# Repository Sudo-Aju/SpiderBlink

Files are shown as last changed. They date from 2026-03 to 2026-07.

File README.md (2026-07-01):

<div align="center">

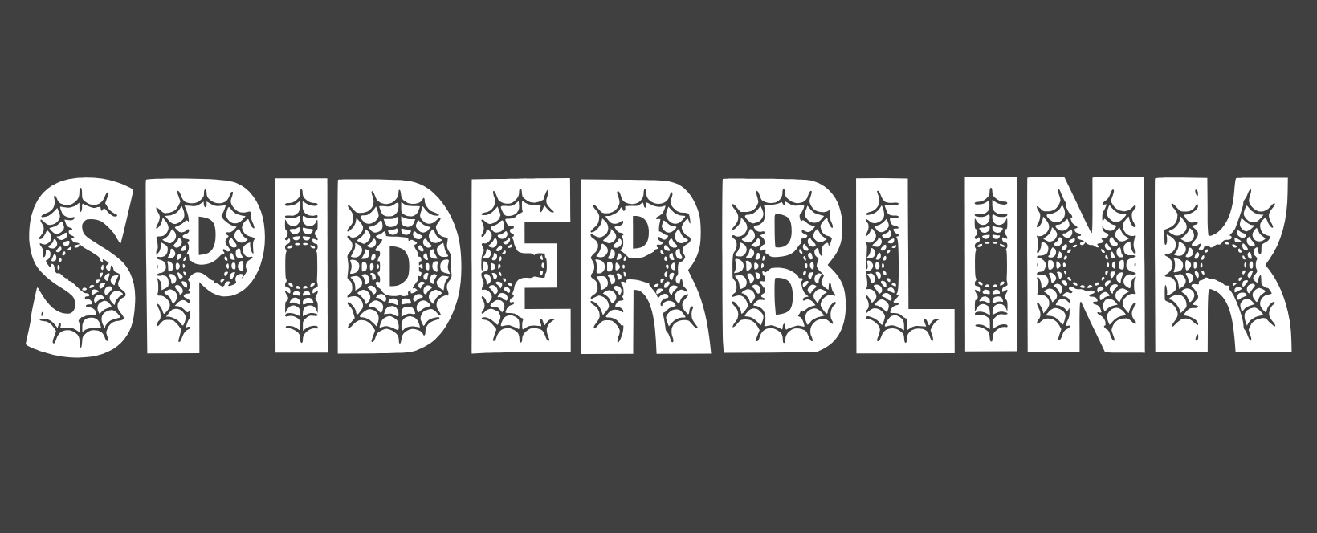
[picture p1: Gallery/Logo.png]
swlogo
# 

A Tiny LED Blinker in Shape of a Spiderweb

<p>



</p>

### _Blinks every time it gets the tingle._

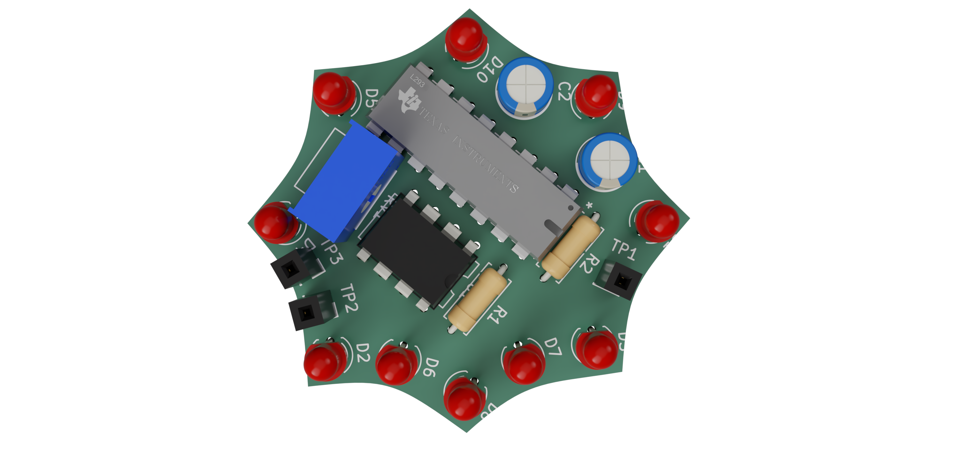
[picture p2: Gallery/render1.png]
  

</p>
</div>

# Overview

**SpiderBlink** is a 555 LED chaser board that blinks 10 LEDs in a variable speed sequence using a **NE555P** timer IC and a **CD4017** decade counter. I built this as a beginner PCB project to learn schematic design, PCB routing, and hands-on soldering.

---

# Gallery

<div align="center">

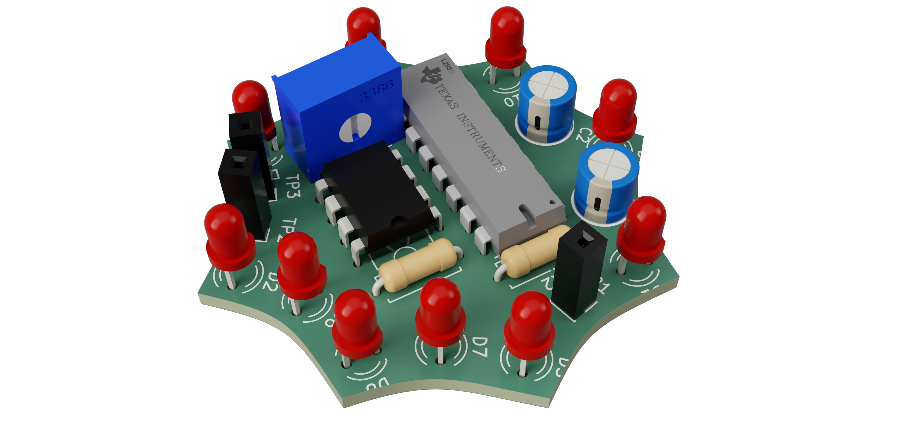
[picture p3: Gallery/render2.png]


</div>

---

# Zine

<div align="center">

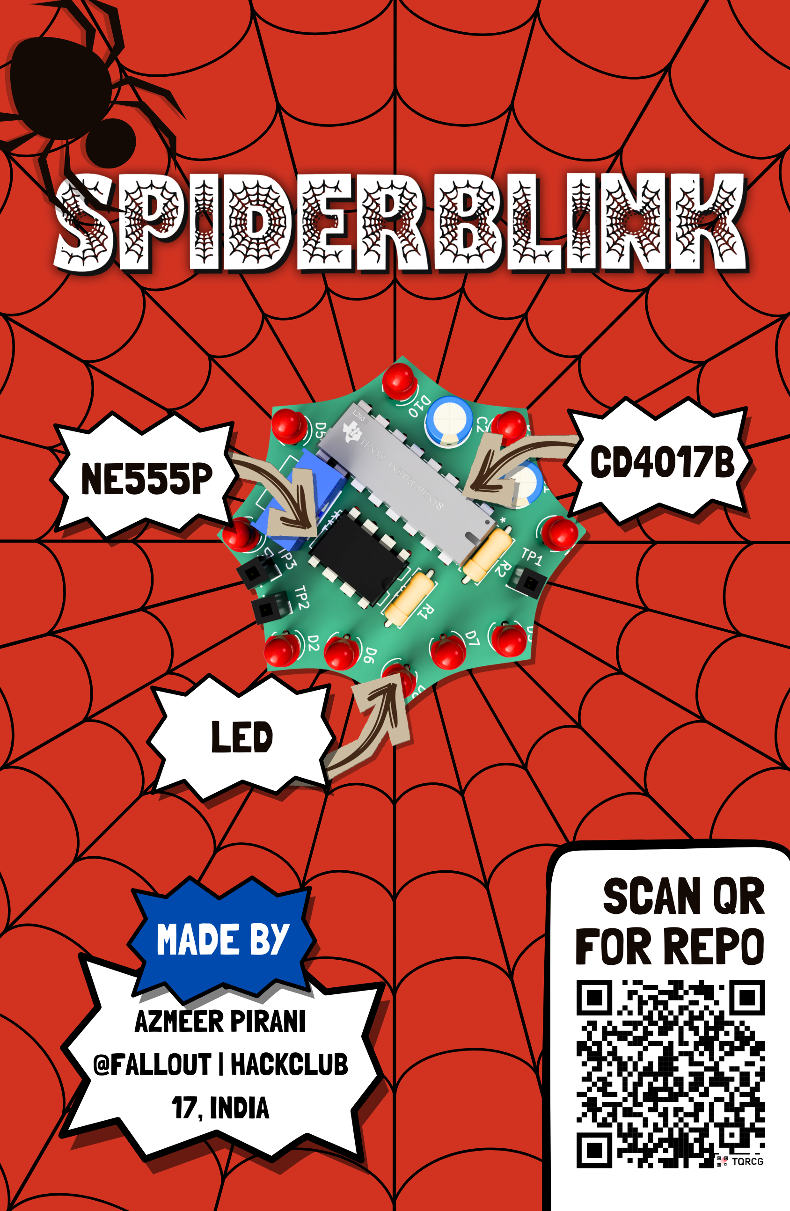
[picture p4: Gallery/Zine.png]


</div>

---

# Motivation

I wanted to dvelve deeper into embedded electronics, so thought this might be the chance for me to understand more about ICs, Timers and Oscillators

---

## Bill of Materials

|Reference|Description |Manufacturer |MPN |Quantity|Supplier |Unit Price (USD)|Extended Price (USD)|Product Link |
|---|---|---|---|---|---|---|---|---|
|C1 |0.01 µF Ceramic Capacitor |Murata |GRM188R71H103KA01D|1 |Murata |0.10 |0.10 |https://www.murata.com/en-global/products/productdetail?partno=GRM188R71H103KA01D|
|C2 |1 µF Ceramic Capacitor |Murata |GRM188R60J105KA01D|1 |Murata |0.15 |0.15 |https://www.murata.com/en-global/products/productdetail?partno=GRM188R60J105KA01D|
|D1-D10 |5 mm Red LED |Kingbright |WP7113ID |10 |Kingbright |0.18 |1.80 |https://www.kingbrightusa.com/product.asp?catalog_name=LED&product_id=WP7113ID |
|R1 |1 kΩ 1/4W Through-Hole Resistor |Yageo |CFR-25JB-52-1K |1 |Yageo |0.02 |0.02 |https://www.yageo.com/en/Product/Search?partNumber=CFR-25JB-52-1K |
|R2 |470 Ω 1/4W Through-Hole Resistor|Yageo |CFR-25JB-52-470R  |1 |Yageo |0.02 |0.02 |https://www.yageo.com/en/Product/Search?partNumber=CFR-25JB-52-470R |
|RV1 |50 kΩ Trimmer Potentiometer |Bourns |3362P-1-503LF |1 |Bourns |1.25 |1.25 |https://www.bourns.com/products/trimpot-trimming-potentiometers/product/3362 |
|U1 |NE555P Timer IC |Texas Instruments|NE555P |1 |Texas Instruments|0.60 |0.60 |https://www.ti.com/product/NE555 |
|U2 |CD4017B Decade Counter |Texas Instruments|CD4017B |1 |Texas Instruments|0.75 |0.75 |https://www.ti.com/product/CD4017B |

---

# Features

- Heartbeat: An NE555 timer generates the clock signal.
- Speed Control: A 50kΩ potentiometer adjusts the LED flashing speed.
- Sequencer: A CD4017 decade counter cycles the signal through 10 steps.
- Rotating Effect: 10 LEDs arranged in a circular pattern for a rotating effect.

---

# PCB Design

The PCB was designed with the reference of a piderweb, more specifically Spiderman

## PCB
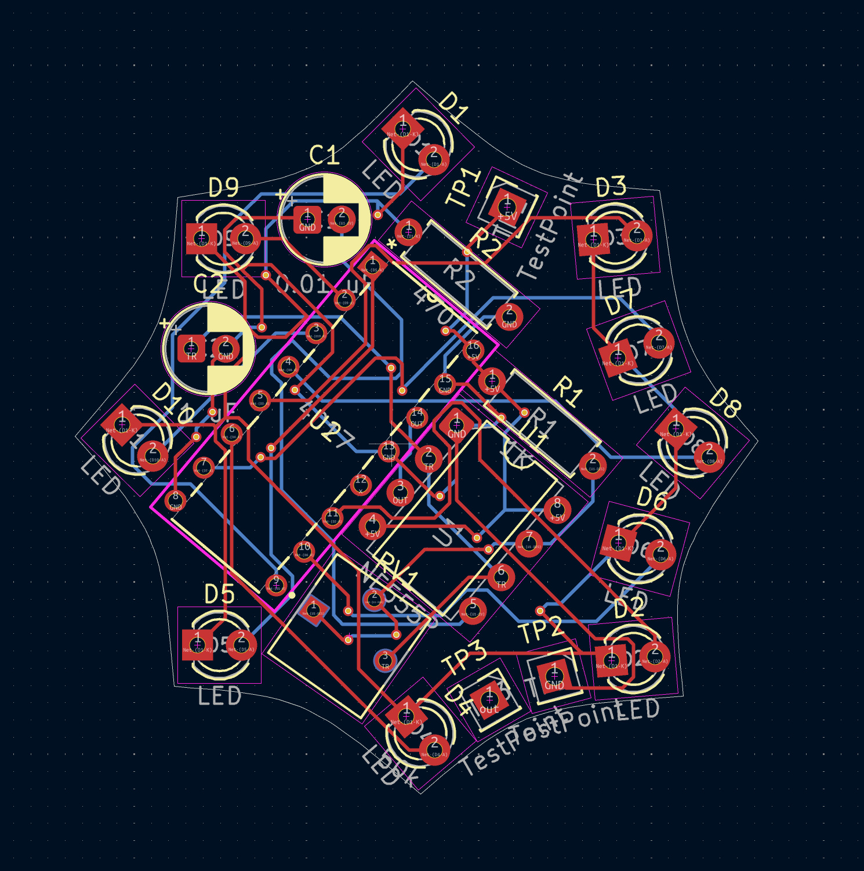
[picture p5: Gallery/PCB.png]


## Schematic
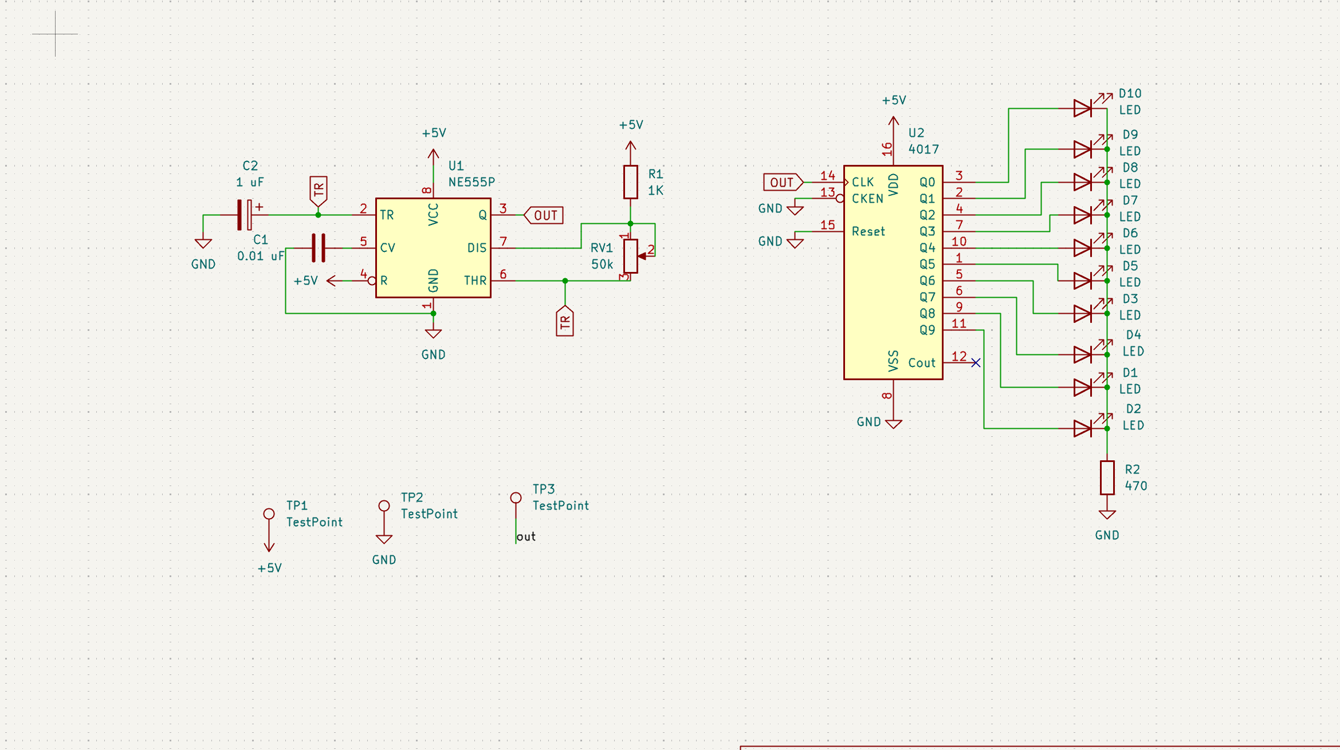
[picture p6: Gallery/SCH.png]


---

# Current Status

- [X] Initial Concept
- [X] Schematic Design
- [X] PCB Design
- [X] Hardware Validation
- [ ] Functional Testing
- [ ] Community Evaluation 

---

# Repository Structure

```bash
SpiderBlink/
├── PCB/
├── BOM.csv
├── Gallery/
└── README.md
```

---

# Assemble Guide

## 1. Order the PCB

Navigate to:

```bash
./PCB/Gerber.zip
```

Upload the Gerber files to your preferred PCB manufacturer.

---

## 2. Order Components

All required components can be found in:

```bash
./PCB/BOM.csv
```

---

## 3. Solder the Components

Recommended assembly should follow a low-profile to high-profile sequence to simplify alignment and reduce rework.

Suggested order:

1. 1/4W Resistors (R1, R2)
2. Ceramic Capacitors (C1, C2)
3. NE555P
4. 5mm LEDs (D1–D10)

---

## 4. Inspect the Board

Before powering:
- Check for shorts
- Verify connections
- Inspect power rails

---

# Contributing

Contributions, suggestions, and feedback are welcome.

If you'd like to improve SpiderBlink:

```bash
git clone https://github.com/Sudo-Aju/SpiderBlink.git
cd SpiderBlink
```

1. Create a feature branch
2. Make your changes
3. Commit your work
4. Open a pull request

---

# Creator

### Azmeer Pirani

Built with ❤️ for:
- Embedded Systems
- PCB Design
- Open Source Hardware
- Tiny Things

---

# License

This project is licensed under the MIT License.

---

<div align="center">

## SPIDERBLINK

### _Blinks every time it gets the tingle._

</div>

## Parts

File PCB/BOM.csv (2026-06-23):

Reference | Description | Manufacturer | MPN | Quantity | Supplier | Unit Price | Currency | Product Link | Extended Price
C1 | 0.01 µF Ceramic Capacitor | Murata | GRM188R71H103KA01D | 1 | Murata | 0.10 | USD | https://www.murata.com/en-global/products/productdetail?partno=GRM188R71H103KA01D | 0.1
C2 | 1 µF Ceramic Capacitor | Murata | GRM188R60J105KA01D | 1 | Murata | 0.15 | USD | https://www.murata.com/en-global/products/productdetail?partno=GRM188R60J105KA01D | 0.15
D1–D10 | 5 mm Red LED | Kingbright | WP7113ID | 10 | Kingbright | 0.18 | USD | https://www.kingbrightusa.com/product.asp?catalog_name=LED&product_id=WP7113ID | 1.7999999999999998
R1 | 1 kΩ 1/4W Resistor | Yageo | CFR-25JB-52-1K | 1 | Yageo | 0.02 | USD | https://www.yageo.com/en/Product/Search?partNumber=CFR-25JB-52-1K | 0.02
R2 | 470 Ω 1/4W Resistor | Yageo | CFR-25JB-52-470R | 1 | Yageo | 0.02 | USD | https://www.yageo.com/en/Product/Search?partNumber=CFR-25JB-52-470R | 0.02
RV1 | 50 kΩ Trimmer Potentiometer | Bourns | 3362P-1-503LF | 1 | Bourns | 1.25 | USD | https://www.bourns.com/products/trimpot-trimming-potentiometers/product/3362 | 1.25
U1 | NE555P Timer IC | Texas Instruments | NE555P | 1 | Texas Instruments | 0.60 | USD | https://www.ti.com/product/NE555 | 0.6
U2 | CD4017B Decade Counter | Texas Instruments | CD4017B | 1 | Texas Instruments | 0.75 | USD | https://www.ti.com/product/CD4017B | 0.75

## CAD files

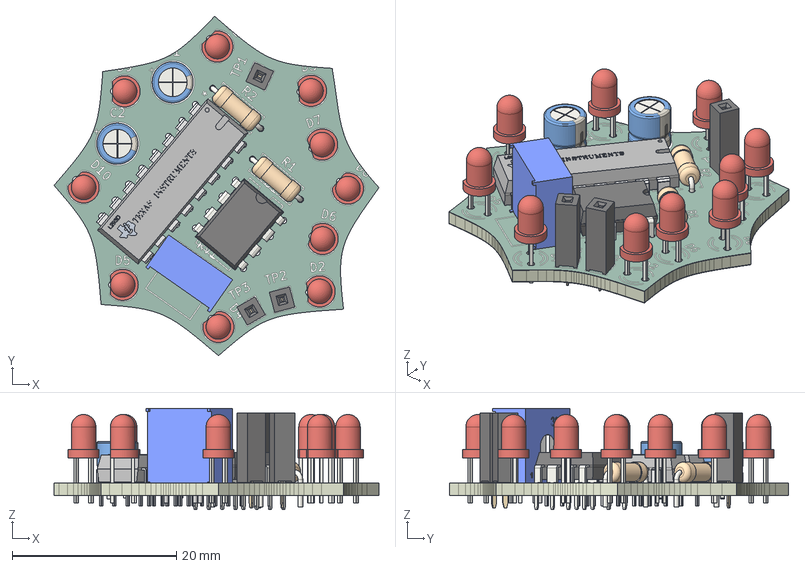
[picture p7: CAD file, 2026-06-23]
PCB/PCB.step
39.6 x 41.4 x 12.3 mm
CP_Radial_D50mm_P200mm x 2
LED_D3.0mm x 10
PinSocket_1x01_P2.54mm_Vertical x 3
IC 16 DIP
IC Leg x 16
L293D
Texas Instrument Logo
Trimpot 3386H v1
R_Axial_DIN0207_L63mm_D25mm_P762mm_Horizontal x 2
DIP-8_W7.62mm
Spider-unsaved-export-1Loybe_silkscreen
Spider-unsaved-export-1Loybe_soldermask x 2
Spider-unsaved-export-1Loybe_PCB

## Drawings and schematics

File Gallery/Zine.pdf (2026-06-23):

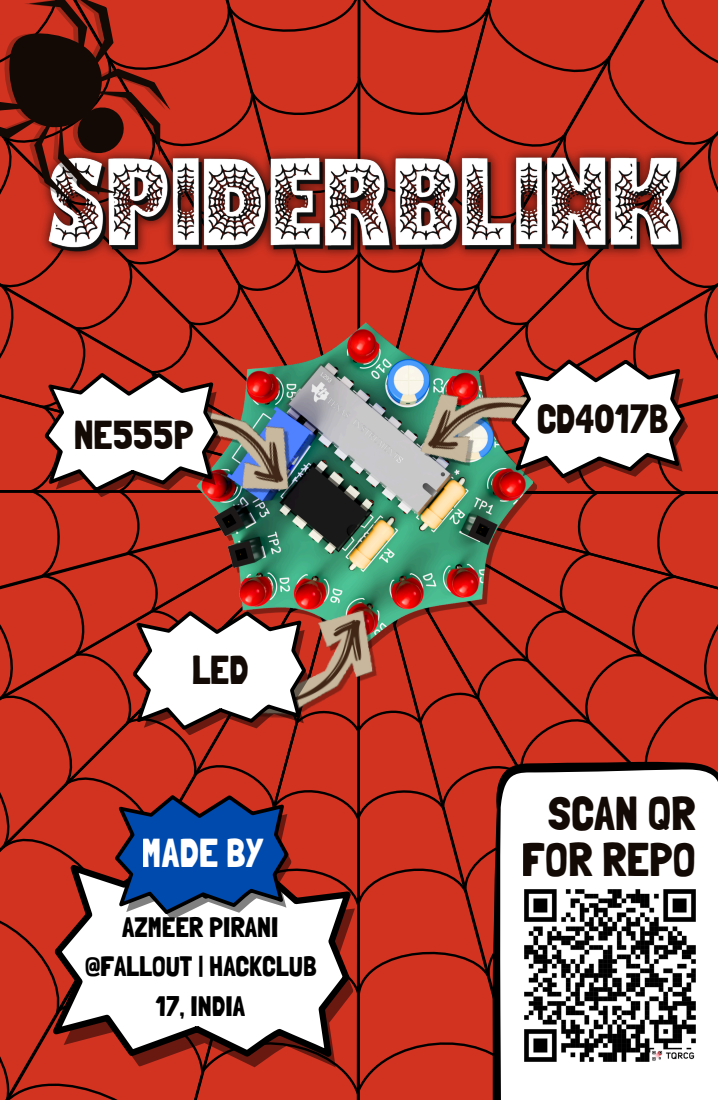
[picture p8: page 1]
AZMEER PIRANI @FALLOUT | HACKCLUB 17, INDIA; MADE BY; SCAN QR FOR REPO; LED

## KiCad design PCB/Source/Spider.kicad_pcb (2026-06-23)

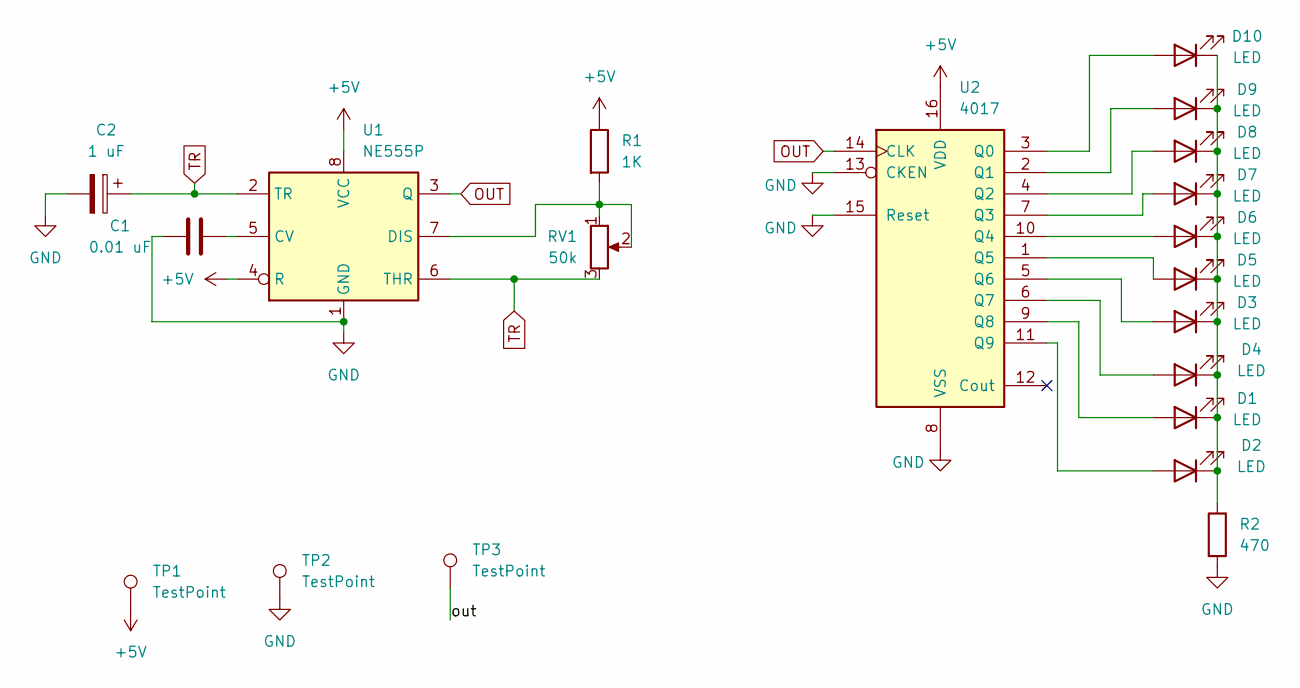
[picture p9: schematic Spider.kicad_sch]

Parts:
C1: 0.01 uF; CP_Radial_D5.0mm_P2.00mm
C2: 1 uF; CP_Radial_D5.0mm_P2.00mm
D1, D2, D3, D4, D5, D6, D7, D8, D9, D10: LED; LED_D3.0mm
R1: 1K; R_Axial_DIN0207_L6.3mm_D2.5mm_P7.62mm_Horizontal
R2: 470; R_Axial_DIN0207_L6.3mm_D2.5mm_P7.62mm_Horizontal
RV1: 50k; TRIM_3362P-1-102
TP1, TP2, TP3: TestPoint; PinSocket_1x01_P2.54mm_Vertical
U1: NE555P; DIP-8_W7.62mm
U2: 4017; N16

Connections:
+5V: R1.1, TP1.1, U1.4 (R), U1.8 (VCC), U2.16 (VDD)
/out: TP3.1
GND: C1.1, C2.2, R2.2, TP2.1, U1.1 (GND), U2.8 (VSS), U2.13 (CKEN), U2.15 (Reset)
unnamed: D1.2 (A), U2.9 (Q8)
unnamed: D1.1 (K), D2.1 (K), D3.1 (K), D4.1 (K), D5.1 (K), D6.1 (K), D7.1 (K), D8.1 (K), D9.1 (K), D10.1 (K), R2.1
unnamed: D2.2 (A), U2.11 (Q9)
unnamed: D3.2 (A), U2.5 (Q6)
unnamed: D4.2 (A), U2.6 (Q7)
unnamed: D5.2 (A), U2.1 (Q5)
unnamed: D6.2 (A), U2.10 (Q4)
unnamed: D7.2 (A), U2.7 (Q3)
unnamed: D8.2 (A), U2.4 (Q2)
unnamed: D9.2 (A), U2.2 (Q1)
unnamed: D10.2 (A), U2.3 (Q0)
unnamed: C1.2, U1.5 (CV)
unnamed: R1.2, RV1.1, RV1.2, U1.7 (DIS)
OUT: U1.3 (Q), U2.14 (CLK)
TR: C2.1, RV1.3, U1.2 (TR), U1.6 (THR)

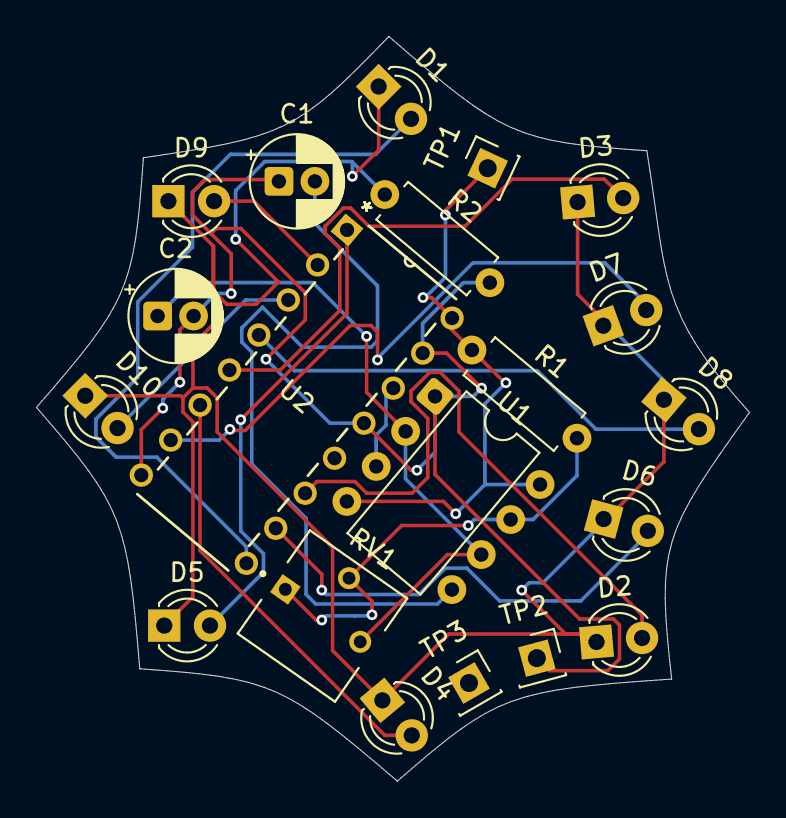
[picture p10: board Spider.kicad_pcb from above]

Board: 2 copper layers, 39.6 x 41.4 mm, 20 parts (0 on the bottom side), 17 nets.

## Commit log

2026-06-23 made lot of updates, changed images, added few sources, and added pcb 3d model
    [PCB.step, Spider.kicad_pcb, Spider.kicad_sch]
2026-06-23 Update Bill of Materials format in README.md
2026-06-23 Updated images, BOM, and project file
    [BOM.csv]
2026-07-01 almost done witht the readme, added features, and currentstatuus
2026-07-01 fully updated the readme and changed the readme locaiton
    [BOM.csv]
